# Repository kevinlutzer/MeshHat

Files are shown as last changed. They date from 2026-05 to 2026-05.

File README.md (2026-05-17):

# MeshHat

> A standard Raspberry Pi HAT with everything needed to run [MeshCore](https://meshcore.io) or [Meshtastic](https://meshtastic.org) — right out of the box.

---

## Overview

MeshHat is a Raspberry Pi HAT (Hardware Attached on Top) that integrates all the components required to join or extend a LoRa mesh network. Whether you're building an internet gateway, running automations, or deploying a remote node, MeshHat gives you a single-board solution with no additional wiring.

---

## Features

| Component | Details |
|---|---|
| **LoRa Module** | E22P — 1W output power |
| **Radio Driver MCU** | RP2040 |
| **Programming Interface** | SWD connector (for RP2040 firmware updates) |
| **Host Interface** | UART0 (Raspberry Pi ↔ RP2040) |
| **Remote Flashing** | SWD lines routed to Raspberry Pi GPIO |

---

## How It Works

Communication between the RP2040 (which handles radio duties) and the Raspberry Pi host runs over **UART0**. The RP2040 can also be **reflashed remotely** via the SWD lines connected to the Pi — no physical access to the board required for firmware updates.

---

## Example Applications

- **Internet Gateway** — Bridge a LoRa mesh network to the internet
- **Mesh Automations** — Trigger actions based on mesh messages or node events
- **Remote Sensor Node** — Deploy a standalone, Pi-powered mesh node

---

## Compatible Firmware

- [MeshCore](https://meshcore.io)
- [Meshtastic](https://meshtastic.org)

---

## Getting Started

> ⚠️ *Documentation in progress. Pinout diagrams, setup guides, and firmware flashing instructions coming soon.*

---

## Contributing

Pull requests and issue reports are welcome. If you've built something with MeshHat, we'd love to hear about it.

---

## License

*To be specified.*

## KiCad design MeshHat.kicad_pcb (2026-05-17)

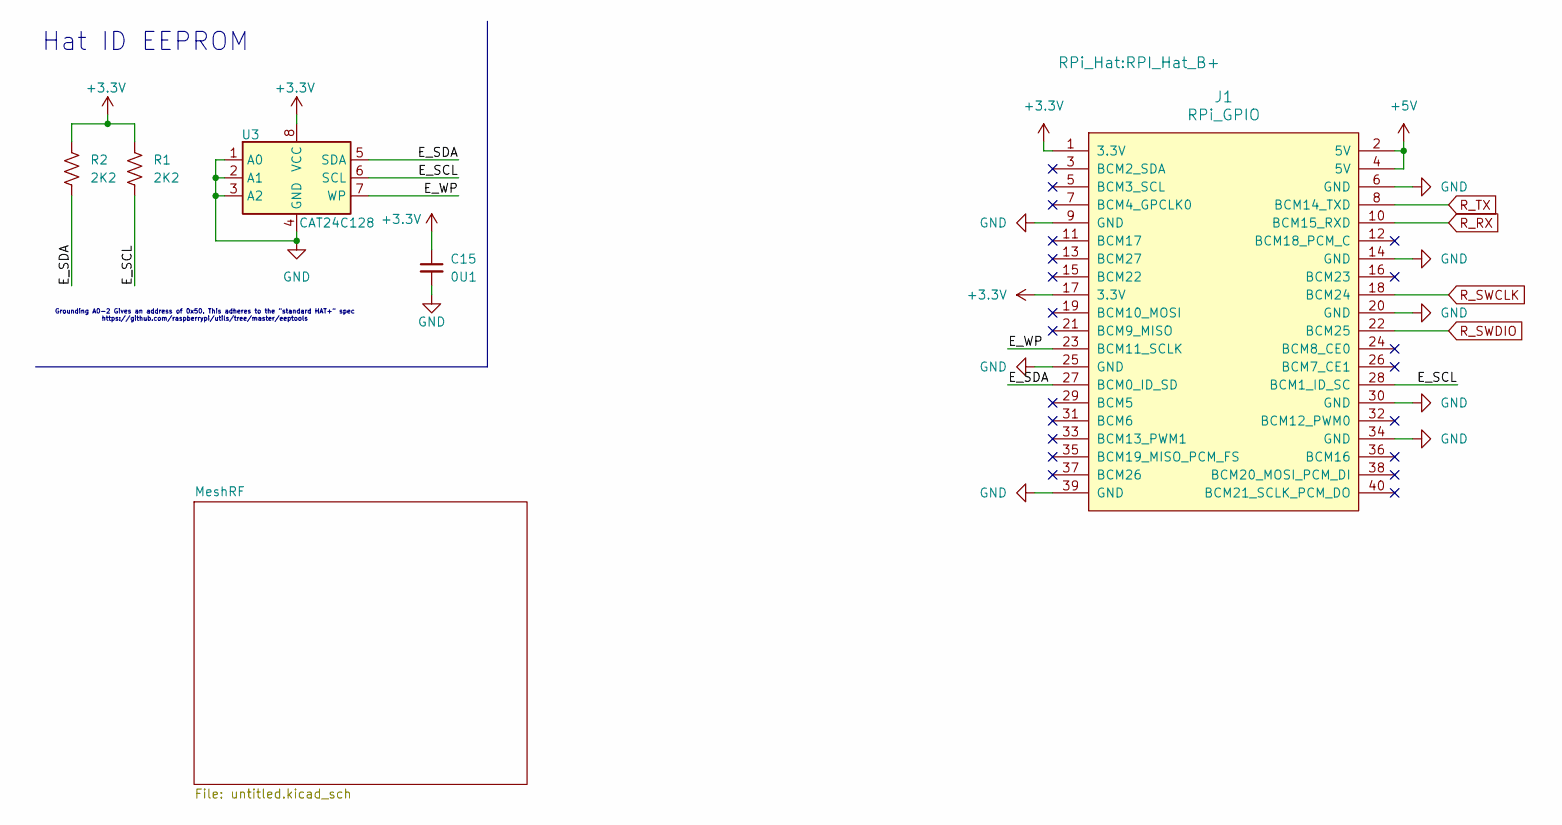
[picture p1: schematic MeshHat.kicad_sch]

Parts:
C15: 0U1; C_0603_1608Metric
J1: RPi_GPIO; RPI_Hat_B+
R1, R2: 2K2; R_0603_1608Metric
U3: CAT24C128; TSSOP-8_4.4x3mm_P0.65mm

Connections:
+3.3V: C15.1, J1.1 (3.3V), J1.17 (3.3V), R1.1, R2.1, U3.8 (VCC); also elsewhere on the board
+5V: J1.2 (5V), J1.4 (5V); also elsewhere on the board
/E_SCL: J1.28 (BCM1_ID_SC), R1.2, U3.6 (SCL)
/E_SDA: J1.27 (BCM0_ID_SD), R2.2, U3.5 (SDA)
/E_WP: J1.23 (BCM11_SCLK), U3.7 (WP)
GND: C15.2, J1.6 (GND), J1.9 (GND), J1.14 (GND), J1.20 (GND), J1.25 (GND), J1.30 (GND), J1.34 (GND), J1.39 (GND), U3.1 (A0), U3.2 (A1), U3.3 (A2), U3.4 (GND); also elsewhere on the board
R_RX: J1.10 (BCM15_RXD); also elsewhere on the board
R_SWCLK: J1.18 (BCM24); also elsewhere on the board
R_SWDIO: J1.22 (BCM25); also elsewhere on the board
R_TX: J1.8 (BCM14_TXD); also elsewhere on the board

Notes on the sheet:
Hat ID EEPROM
Grounding A0-2 Gives an address of 0x50. This adheres to the "standard HAT+" spec https://github.com/raspberrypi/utils/tree/master/eeptools

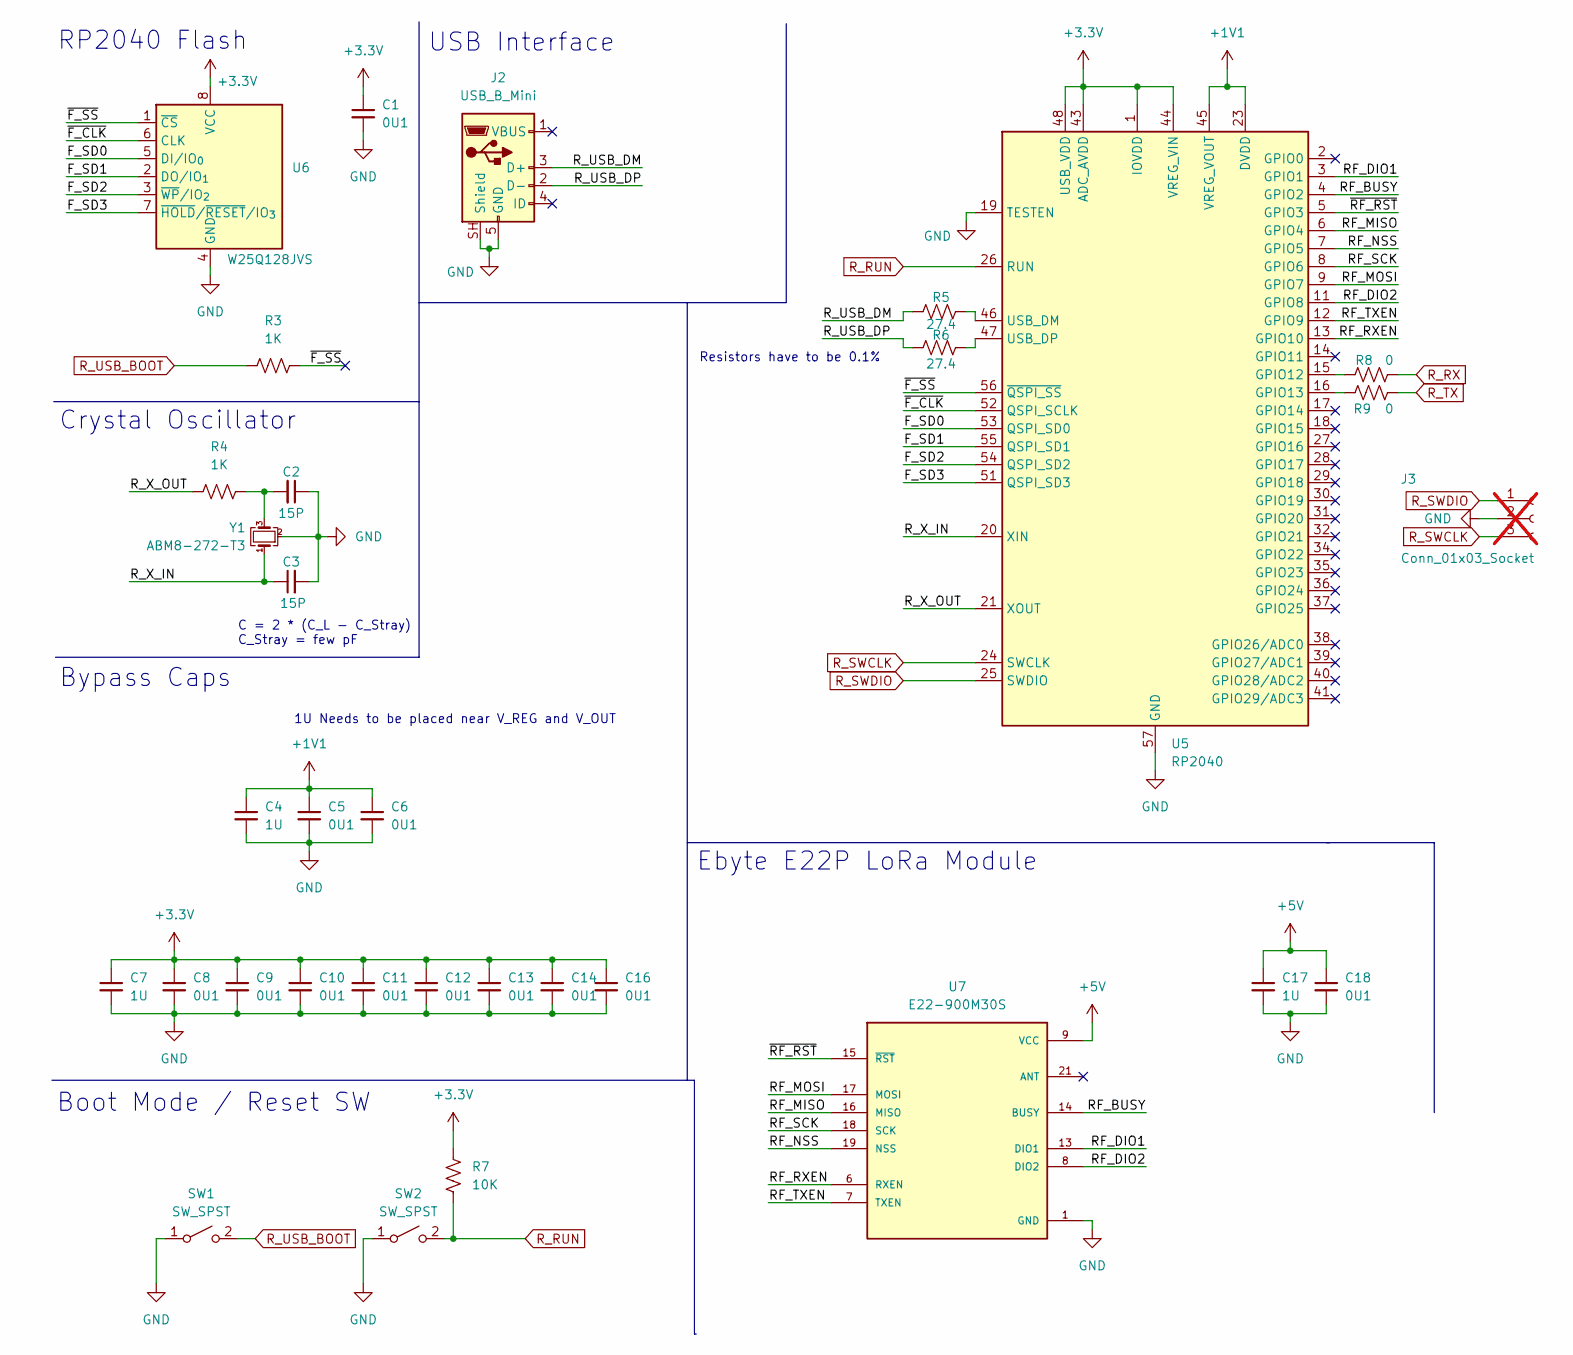
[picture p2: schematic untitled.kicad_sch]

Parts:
C1, C5, C6, C8, C9, C10, C11, C12, C13, C14, C16, C18: 0U1; C_0603_1608Metric
C2, C3: 15P; C_0603_1608Metric
C4, C7, C17: 1U; C_0603_1608Metric
J2: USB_B_Mini; USB_Mini-B_AdamTech_MUSB-B5-S-VT-TSMT-1_SMD_Vertical
J3: Conn_01x03_Socket; JST_SH_BM03B-SRSS-TB_1x03-1MP_P1.00mm_Vertical; not fitted
R3, R4: 1K; R_0603_1608Metric
R5, R6: 27.4; R_0603_1608Metric
R7: 10K; R_0603_1608Metric
R8, R9: 0; R_0603_1608Metric
SW1, SW2: SW_SPST; SW_Push_1P1T_NO_CK_KMR2
U5: RP2040; QFN-56-1EP_7x7mm_P0.4mm_EP3.2x3.2mm
U6: W25Q128JVS; SOIC-8_5.3x5.3mm_P1.27mm
U7: E22-900M30S; XCVR_E22-900M30S; PARTREV 1.2
Y1: ABM8-272-T3; Crystal_SMD_Abracon_ABM8G-4Pin_3.2x2.5mm

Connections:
+1V1: C4.1, C5.1, C6.1, U5.23 (DVDD), U5.45 (VREG_VOUT), U5.50 (DVDD)
+3.3V: C1.1, C7.1, C8.1, C9.1, C10.1, C11.1, C12.1, C13.1, C14.1, C16.1, R7.2, U5.1 (IOVDD), U5.10 (IOVDD), U5.22 (IOVDD), U5.33 (IOVDD), U5.42 (IOVDD), U5.43 (ADC_AVDD), U5.44 (VREG_VIN), U5.48 (USB_VDD), U5.49 (IOVDD), U6.8 (VCC); also elsewhere on the board
+5V: C17.1, C18.1, U7.9 (VCC), U7.10 (VCC); also elsewhere on the board
/MeshRF/F_SD0: U5.53 (QSPI_SD0), U6.5 (DI/IO_{0})
/MeshRF/F_SD1: U5.55 (QSPI_SD1), U6.2 (DO/IO_{1})
/MeshRF/F_SD2: U5.54 (QSPI_SD2), U6.3 (~WP/IO_{2})
/MeshRF/F_SD3: U5.51 (QSPI_SD3), U6.7 (~HOLD/~RESET/IO_{3})
/MeshRF/RF_BUSY: U5.4 (GPIO2), U7.14 (BUSY)
/MeshRF/RF_DIO1: U5.3 (GPIO1), U7.13 (DIO1)
/MeshRF/RF_DIO2: U5.11 (GPIO8), U7.8 (DIO2)
/MeshRF/RF_MISO: U5.6 (GPIO4), U7.16 (MISO)
/MeshRF/RF_MOSI: U5.9 (GPIO7), U7.17 (MOSI)
/MeshRF/RF_NSS: U5.7 (GPIO5), U7.19 (NSS)
/MeshRF/RF_RXEN: U5.13 (GPIO10), U7.6 (RXEN)
/MeshRF/RF_SCK: U5.8 (GPIO6), U7.18 (SCK)
/MeshRF/RF_TXEN: U5.12 (GPIO9), U7.7 (TXEN)
/MeshRF/R_USB_DM: J2.3 (D+), R5.1
/MeshRF/R_USB_DP: J2.2 (D-), R6.1
/MeshRF/R_X_IN: C3.1, U5.20 (XIN), Y1.1
/MeshRF/R_X_OUT: R4.1, U5.21 (XOUT)
/MeshRF/~F_CLK: U5.52 (QSPI_SCLK), U6.6 (CLK)
/MeshRF/~F_SS: R3.2, U5.56 (~QSPI_SS), U6.1 (~CS)
/MeshRF/~RF_RST: U5.5 (GPIO3), U7.15 (~RST)
GND: C1.2, C2.1, C3.2, C4.2, C5.2, C6.2, C7.2, C8.2, C9.2, C10.2, C11.2, C12.2, C13.2, C14.2, C16.2, C17.2, C18.2, J2.5 (GND), J2.SH (Shield), J3.2, SW1.1 (A), SW2.1 (A), U5.19 (TESTEN), U5.57 (GND), U6.4 (GND), U7.1 (GND), U7.2 (GND), U7.3 (GND), U7.4 (GND), U7.5 (GND), U7.11 (GND), U7.12 (GND), U7.20 (GND), U7.22 (GND), Y1.2 (G), Y1.4 (G); also elsewhere on the board
unnamed: C2.2, R4.2, Y1.3
unnamed: R8.1, U5.15 (GPIO12)
unnamed: R9.1, U5.16 (GPIO13)
unnamed: R5.2, U5.46 (USB_DM)
unnamed: R6.2, U5.47 (USB_DP)
R_RUN: R7.1, SW2.2 (B), U5.26 (RUN)
R_RX: R8.2; also elsewhere on the board
R_SWCLK: J3.3, U5.24 (SWCLK); also elsewhere on the board
R_SWDIO: J3.1, U5.25 (SWDIO); also elsewhere on the board
R_TX: R9.2; also elsewhere on the board
R_USB_BOOT: R3.1, SW1.2 (B)

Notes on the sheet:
Bypass Caps
Ebyte E22P LoRa Module
RP2040 Flash
C = 2 * (C_L - C_Stray) C_Stray = few pF
Crystal Oscillator
Resistors have to be 0.1%
Boot Mode / Reset SW
USB Interface
1U Needs to be placed near V_REG and V_OUT

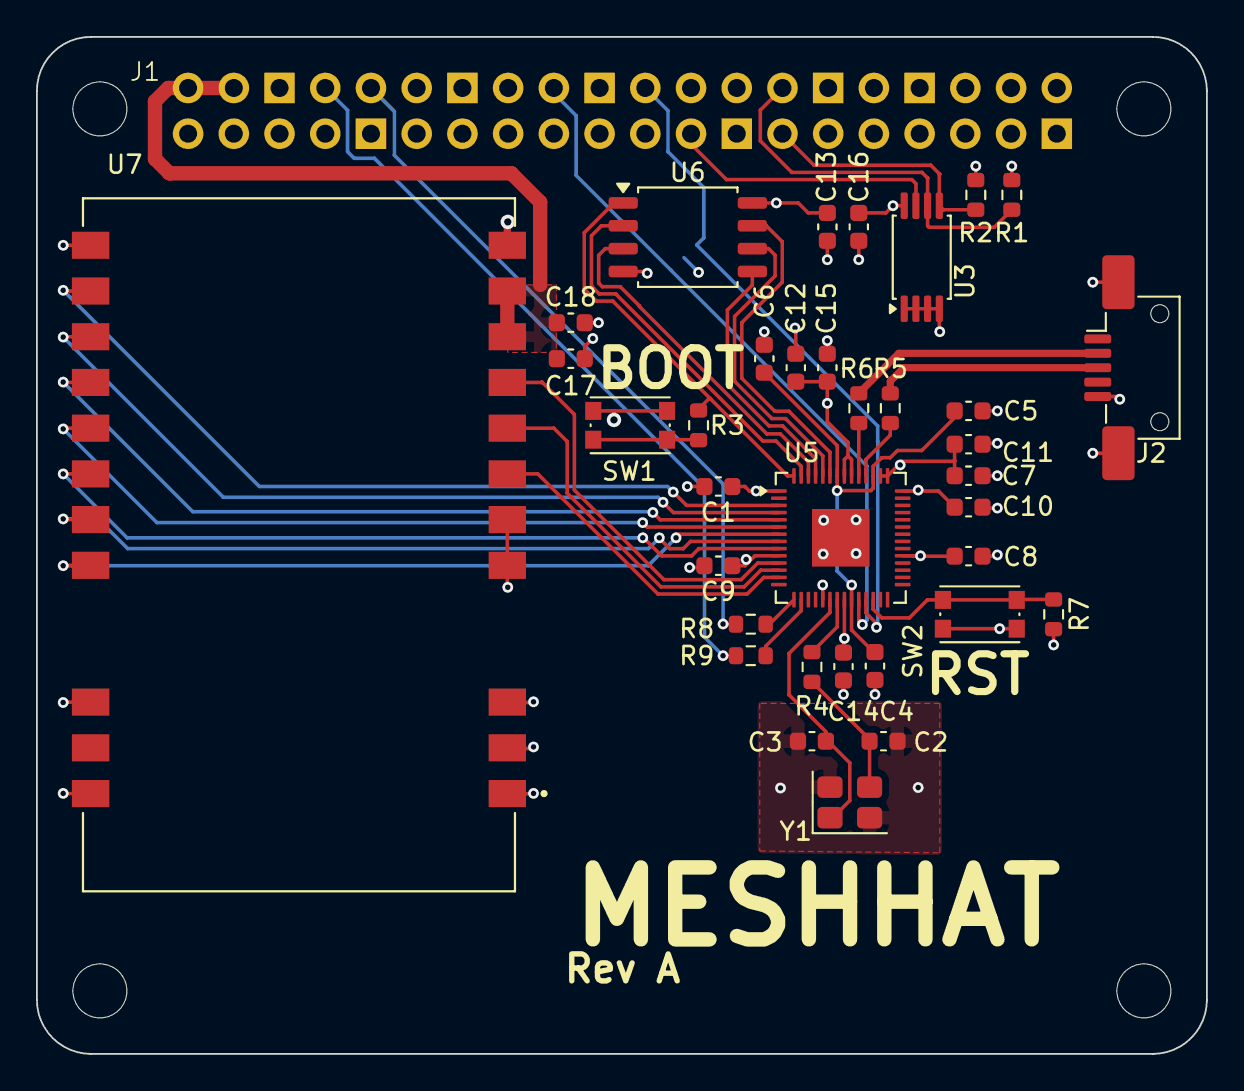
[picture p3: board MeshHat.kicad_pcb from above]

Board: 4 copper layers, 65.0 x 56.5 mm, 37 parts (1 on the bottom side), 38 nets.

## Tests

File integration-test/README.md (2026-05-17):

# Getting Started

Run all of these commands on a 5B. Make sure swclk is connected to pin 24 and swdio is connected to 25

``` bash
# Install the arduino cli 
curl -fsSL https://raw.githubusercontent.com/arduino/arduino-cli/master/install.sh | sh # Add the binary to your path

# setup packages for openocd
sudo apt update -y && sudo apt install -y git make pkg-config autoconf libtool libusb-1.0-0-dev libhidapi-dev gcc g++ libgpiod-dev libjim-dev

# clone openocd and build
git clone https://github.com/raspberrypi/openocd.git --branch rpi-common --depth=1
cd openocd
./bootstrap
./configure --enable-linuxgpiod --disable-werror
sudo make -j4
sudo make install 

# Run openocd to verify the Pico can be reached
sudo openocd -f rpi-swd.cfg -f target/rp2040.cfg -c "adapter speed 100" -c "init" -c "targets" -c "exit" 2>&1

# Setup Arduino CLI for the RP2040
arduino-cli core update-index
arduino-cli config add board_manager.additional_urls \
  https://github.com/earlephilhower/arduino-pico/releases/download/global/package_rp2040_index.json
arduino-cli core update-index
arduino-cli core install rp2040:rp2040

# Setup and build binary
cd ~/
arduino-cli sketch new Blink
cd Blink

cat > Blink.ino << 'EOF'
void setup() {
  pinMode(LED_BUILTIN, OUTPUT);
}

void loop() {
  digitalWrite(LED_BUILTIN, HIGH);
  delay(1000);
  digitalWrite(LED_BUILTIN, LOW);
  delay(1000);
}
EOF

arduino-cli compile -b rp2040:rp2040:rpipico Blink --output-dir=.

# Setup config
cat > rpi-swd.cfg << 'EOF'
adapter driver linuxgpiod
transport select swd
adapter gpio swclk 24 -chip 4
adapter gpio swdio 25 -chip 4
adapter speed 1000
EOF

# Program Binary
sudo openocd -f rpi-swd.cfg -f target/rp2040.cfg -c "program Blink.ino.elf verify reset exit"
```

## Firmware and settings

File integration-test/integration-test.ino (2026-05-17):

#include <RadioLib.h>
#include <SPI.h>

static constexpr uint8_t NSS = 5;  // GPIO4  – SPI0 RX
static constexpr uint8_t DIO1 = 1;  // GPIO5  – SPI0 TX
static constexpr uint8_t NRST = 3;   // GPIO6  – SPI0 SCK
static constexpr uint8_t BUSY = 2;   // GPIO7  – chip-select (active LOW)

static constexpr uint8_t RF_PIN_MISO = 4;  // GPIO4  – SPI0 RX
static constexpr uint8_t RF_PIN_MOSI = 7;  // GPIO5  – SPI0 TX
static constexpr uint8_t RF_PIN_SCK = 6;   // GPIO6  – SPI0 SCK

SX1262 radio = new Module(NSS, DIO1, NRST, BUSY);

// save transmission states between loops
int transmissionState = RADIOLIB_ERR_NONE;

// flag to indicate transmission or reception state
bool transmitFlag = false;

// flag to indicate that a packet was sent or received
volatile bool operationDone = false;

// the setup function runs once when you press reset or power the board
void setup() {
  Serial.begin(9600);
  Serial1.begin(115200);
  Serial1.setRX(pin_size_t pin);
  Serial1.setTX(pin_size_t pin);

  delay(4000);

  SPI.setMISO(RF_PIN_MISO);
  SPI.setMOSI(RF_PIN_MOSI);
  SPI.setSCK(RF_PIN_SCK);   

  // initialize digital pin LED_BUILTIN as an output.
  pinMode(LED_BUILTIN, OUTPUT);

  int state = radio.begin();
  if (state == RADIOLIB_ERR_NONE) {
    Serial.println(F("success!"));
  } else {
    Serial.print(F("failed, code "));
    Serial.println(state);
    while (true) { delay(10); }
  }

  // send the first packet on this node
  Serial.print(F("[SX1262] Sending first packet ... "));
  transmissionState = radio.startTransmit("Hello World!");
  transmitFlag = true;

  // start listening for LoRa packets on this node
  Serial.print(F("[SX1262] Starting to listen ... "));
  state = radio.startReceive();
  if (state == RADIOLIB_ERR_NONE) {
    Serial.println(F("success!"));
  } else {
    Serial.print(F("failed, code "));
    Serial.println(state);
    while (true) { delay(10); }
  }

}

// the loop function runs over and over again forever
void loop() {
  Serial.printf("What the heck %d\n", radio.randomByte());
  digitalWrite(LED_BUILTIN, LOW);  // turn the LED on (HIGH is the voltage level)
  delay(500);                      // wait for a second
  digitalWrite(LED_BUILTIN, LOW);   // turn the LED off by making the voltage LOW
  delay(500);                      // wait for a second
}

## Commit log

2026-04-10 first commit - build most of the schematic
    [MeshHat.kicad_pcb, MeshHat.kicad_sch, untitled.kicad_sch]
2026-04-10 add the rest of the components and the OCD connections
    [MeshHat.kicad_pcb, MeshHat.kicad_sch, untitled.kicad_sch]
2026-04-12 place all components
    [MeshHat.kicad_pcb, MeshHat.kicad_sch, untitled.kicad_sch]
2026-04-12 more of the layout
    [MeshHat.kicad_pcb, MeshHat.kicad_sch, untitled.kicad_sch]
2026-04-16 route more of the layout
    [MeshHat.kicad_pcb, MeshHat.kicad_sch, untitled.kicad_sch]
2026-04-21 update schematic to files and add integration test
    [MeshHat.kicad_sch, untitled.kicad_sch]
2026-04-21 more cleanup of the schematic
    [MeshHat.kicad_pcb, MeshHat.kicad_sch, untitled.kicad_sch]
2026-05-03 add integration test arduino script
    [MeshHat.kicad_pcb, MeshHat.kicad_sch, untitled.kicad_sch]
2026-05-04 get most of the changes in
    [MeshHat.kicad_pcb, MeshHat.kicad_sch, untitled.kicad_sch]
2026-05-07 re-route the swdio lines
    [MeshHat.kicad_pcb, MeshHat.kicad_sch, untitled.kicad_sch]
2026-05-17 finish off PCB, prep for review
    [MeshHat.kicad_pcb, untitled.kicad_sch]
